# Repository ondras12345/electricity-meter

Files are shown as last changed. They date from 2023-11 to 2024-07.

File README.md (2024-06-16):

# Electricity meter
An STM32-based datalogger for electricity meters with pulse LED.

This repository contains both the PCB design files and firmware source code.

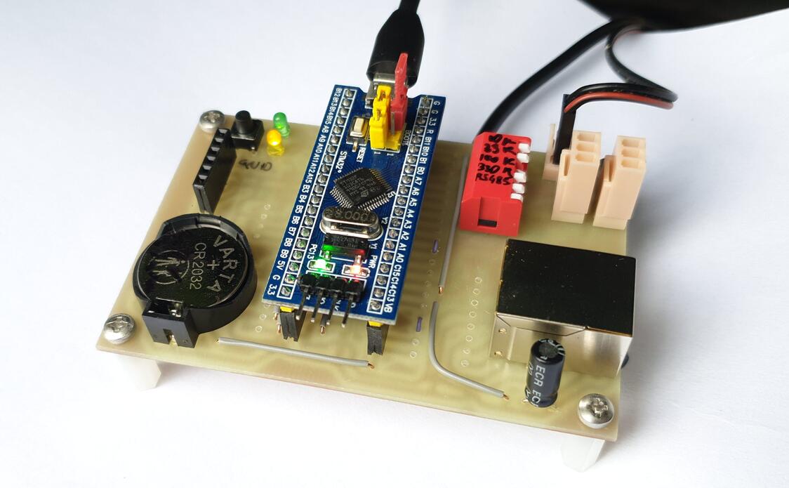
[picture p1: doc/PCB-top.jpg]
Assembled PCB

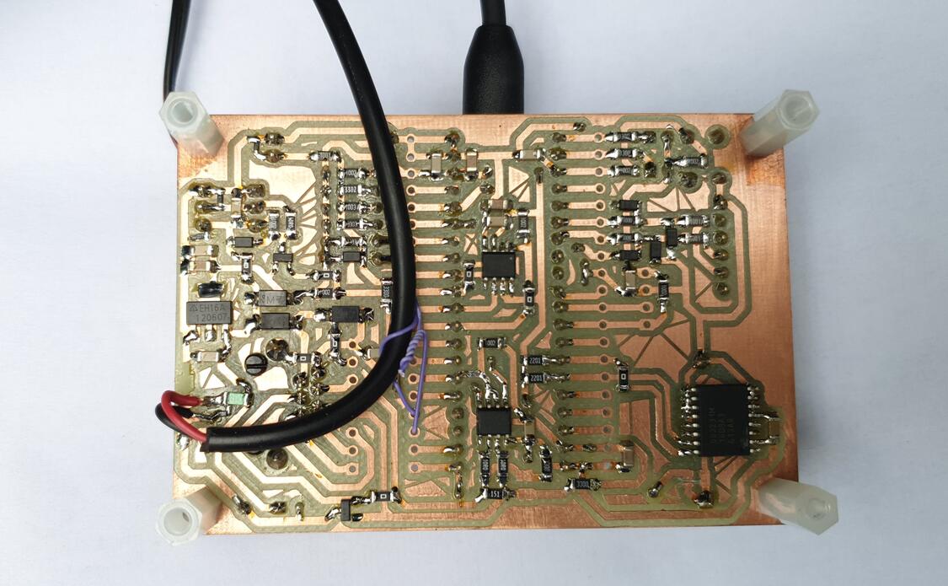
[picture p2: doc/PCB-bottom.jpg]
Bottom side of PCB


## Features
- detecting pulses of LED more than 100 mm away from the sensor,
- dynamic adjustment of bright / dark threshold,
- logging over one year of 1 minute resolution data to SPI flash,
- command line interface for debugging and reading logged data over USB CDC,
- support for RS485 communication.

## Building
### Hardware
I milled the single sided PCB on my [CNC machine](https://github.com/ondras12345/CNC).

Some notes:
- The DCF-3850N connector is only there for future-proofing. I don't currently
  use it and never tested it.
- The onewire bus connector is currently unused, but it should be easy enough
  to add DS18B20 temperature sensors.
- DS3231 RTC is necessary because the internal RTC on my STM32F103 was not
  accurate enough. Cut JP1 (battery power to STM32 VBAT) if you decide to use
  it too.
- The micro USB connector was a bad idea. I ended up replacing it with wires
  soldered directly to the board after accidentally breaking it off several
  times.

### Firmware
```sh
make help  # show available commands
make  # build
make check  # run cppcheck
```

For uploading to the STM32 via STlink, I use `tools/mkbin` and
`tools/upload_latest`.

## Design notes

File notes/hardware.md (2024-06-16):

- RTC
  - internal? (low stability)
    - DCF77 receiver?
  - external DS3231?
- UART / USB
  - USB-CDC is way faster
- 1x ADC for pulse input
  - automatic threshold - see [`automatic-threshold.ipynb`](automatic-threshold.ipynb)
- SPI flash || SD card || both
- DIP switches (pull-up value)
  - TODO make it software configurable instead? (only VCC-0.4V)
- ATmega8
  - - needs external RTC
  - - too little flash space
  - - needs 3v3 converter for SPI flash & SD card
  - + lots of them
  - USART can go faster https://arduino.stackexchange.com/questions/296/how-high-of-a-baud-rate-can-i-go-without-errors
- STM32F103
  - - more expensive
  - - power consumption?
  - - physically bigger
  - + has RTC (precision?, external crystal?)
  - + USB CDC
  - + higher ADC resolution
  - + 3v3 SD card
  - + enough flash for fully featured command line
- RS485 modbus? - would need optical isolation
  - https://github.com/arduino-libraries/ArduinoModbus
  - https://github.com/arduino-libraries/ArduinoRS485

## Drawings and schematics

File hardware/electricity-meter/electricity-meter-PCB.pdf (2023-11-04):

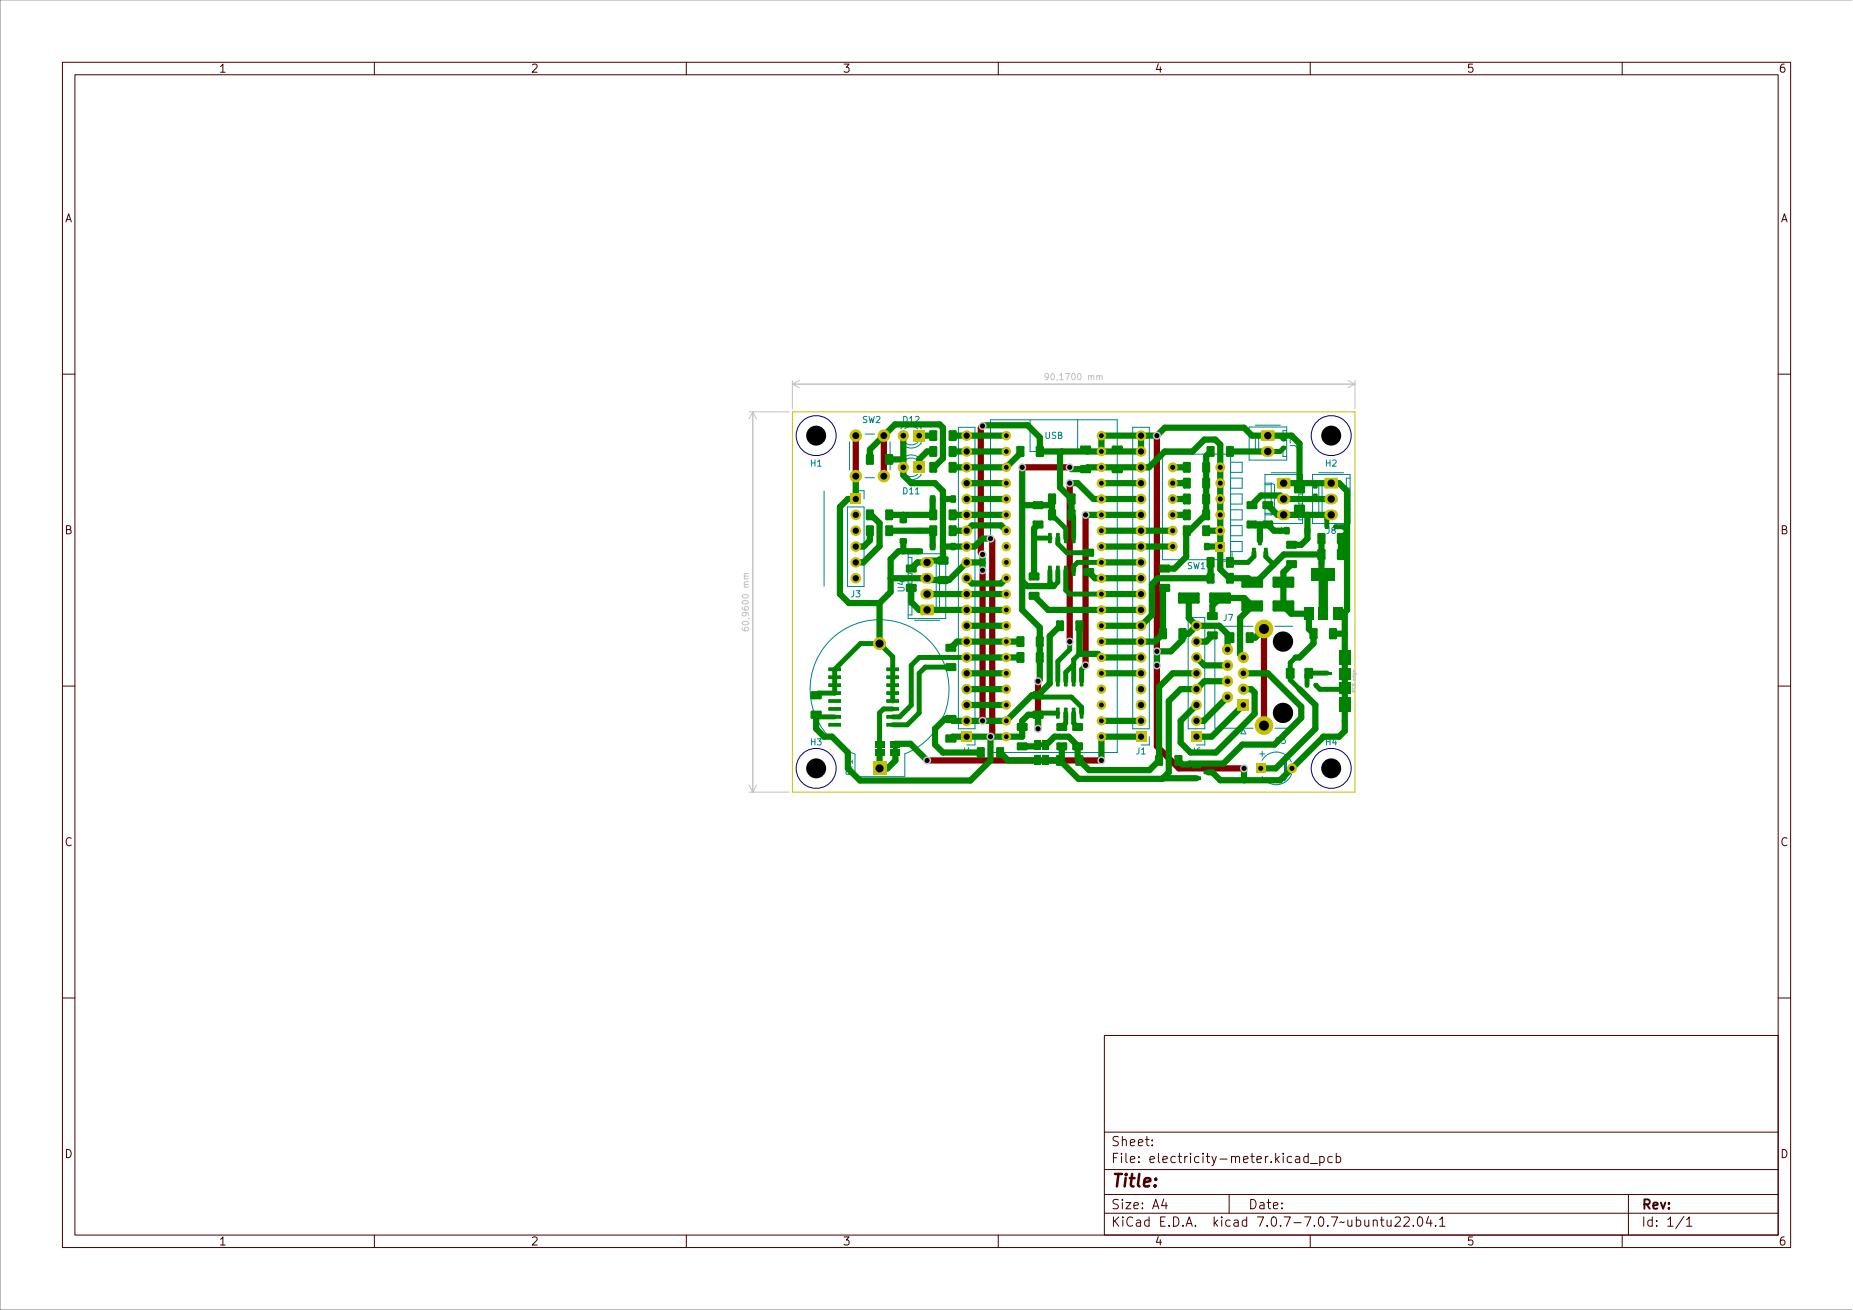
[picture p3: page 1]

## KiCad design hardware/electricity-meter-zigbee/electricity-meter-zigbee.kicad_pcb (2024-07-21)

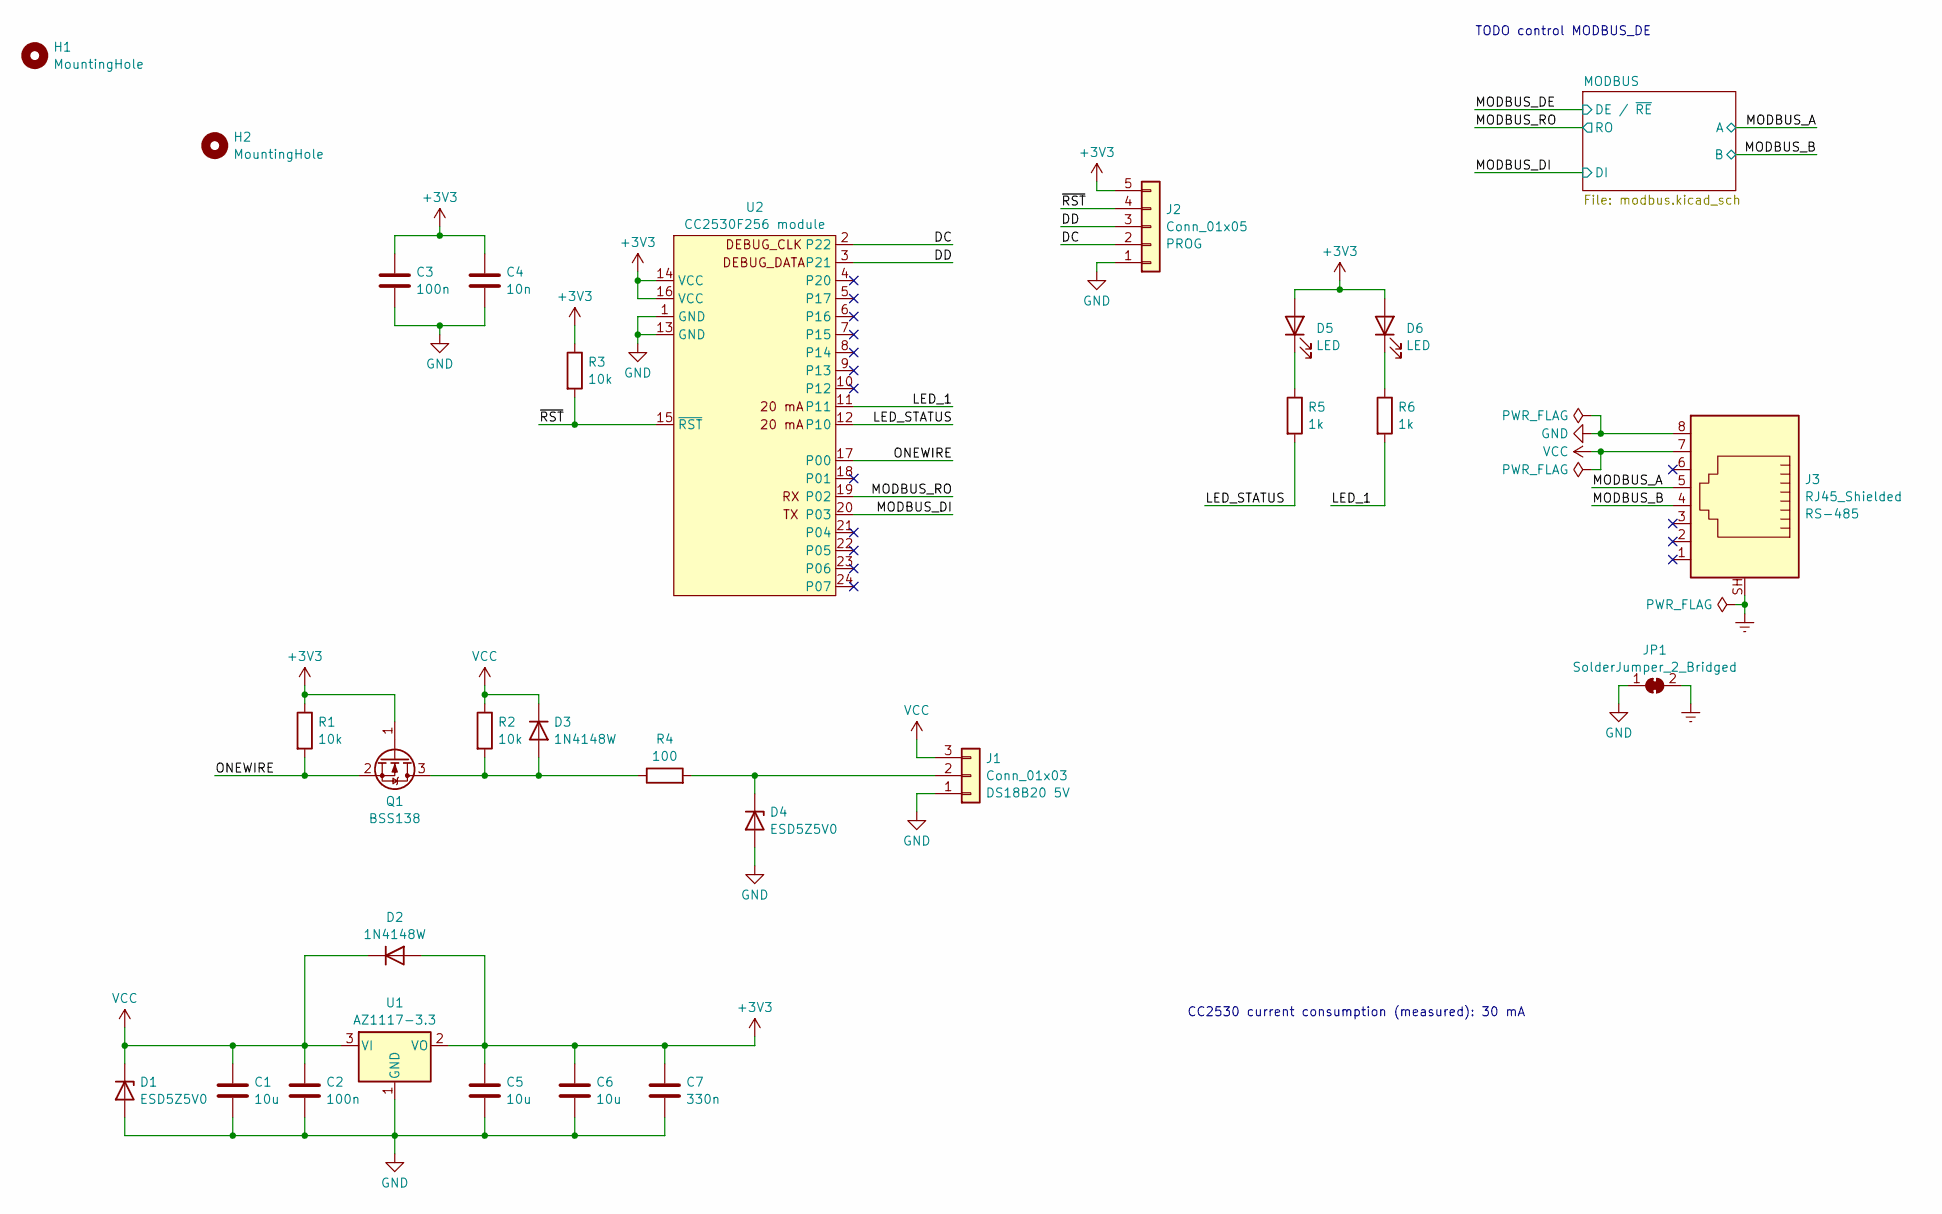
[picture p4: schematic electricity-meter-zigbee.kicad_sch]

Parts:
C1, C5, C6: 10u; C_1206_3216Metric_Pad1.33x1.80mm_HandSolder
C2, C3: 100n; C_1206_3216Metric_Pad1.33x1.80mm_HandSolder
C4: 10n; C_1206_3216Metric_Pad1.33x1.80mm_HandSolder
C7: 330n; C_1206_3216Metric_Pad1.33x1.80mm_HandSolder
D1, D4: ESD5Z5V0; D_SOD-523
D2, D3: 1N4148W; D_SOD-123
D5, D6: LED; LED_D3.0mm
H1, H2: MountingHole; MountingHole_3.2mm_M3
J1: Conn_01x03; Molex_KK-254_AE-6410-03A_1x03_P2.54mm_Vertical
J2: Conn_01x05; Molex_KK-254_AE-6410-05A_1x05_P2.54mm_Vertical
J3: RJ45_Shielded; RJ45_HALO_HFJ11-x2450HRL_Horizontal
JP1: SolderJumper_2_Bridged; SolderJumper-2_P1.3mm_Bridged_RoundedPad1.0x1.5mm
Q1: BSS138; SOT-23
R1, R2, R3: 10k; R_1206_3216Metric_Pad1.30x1.75mm_HandSolder
R4: 100; R_1206_3216Metric_Pad1.30x1.75mm_HandSolder
R5, R6: 1k; R_1206_3216Metric_Pad1.30x1.75mm_HandSolder
U1: AZ1117-3.3; SOT-223-3_TabPin2
U2: CC2530F256 module; CC2530F256_module

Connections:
+3V3: C3.1, C4.1, C5.1, C6.1, C7.1, D2.2 (A), D5.2 (A), D6.2 (A), J2.5, Q1.1 (G), R1.1, R3.1, U1.2 (VO), U2.14 (VCC), U2.16 (VCC); also elsewhere on the board
/DC: J2.2, U2.2 (P22)
/DD: J2.3, U2.3 (P21)
/LED_1: R6.2, U2.11
/LED_STATUS: R5.2, U2.12 (P10)
/MODBUS_A: J3.5; also elsewhere on the board
/MODBUS_B: J3.4; also elsewhere on the board
/MODBUS_DI: U2.20 (P03); also elsewhere on the board
/MODBUS_RO: U2.19 (P02); also elsewhere on the board
/ONEWIRE: Q1.2 (S), R1.2, U2.17 (P00)
/~RST: J2.4, R3.2, U2.15 (~RST)
Earth: J3.SH, JP1.2 (B)
GND: C1.2, C2.2, C3.2, C4.2, C5.2, C6.2, C7.2, D1.2 (A), D4.2 (A), J1.1, J2.1, J3.8, JP1.1 (A), U1.1 (GND), U2.1 (GND), U2.13 (GND); also elsewhere on the board
unnamed: D3.2 (A), Q1.3 (D), R2.2, R4.1
unnamed: D4.1 (K), J1.2, R4.2
unnamed: D5.1 (K), R5.1
unnamed: D6.1 (K), R6.1
VCC: C1.1, C2.1, D1.1 (K), D2.1 (K), D3.1 (K), J1.3, J3.7, R2.1, U1.3 (VI)

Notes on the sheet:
TODO control MODBUS_DE
CC2530 current consumption (measured): 30 mA

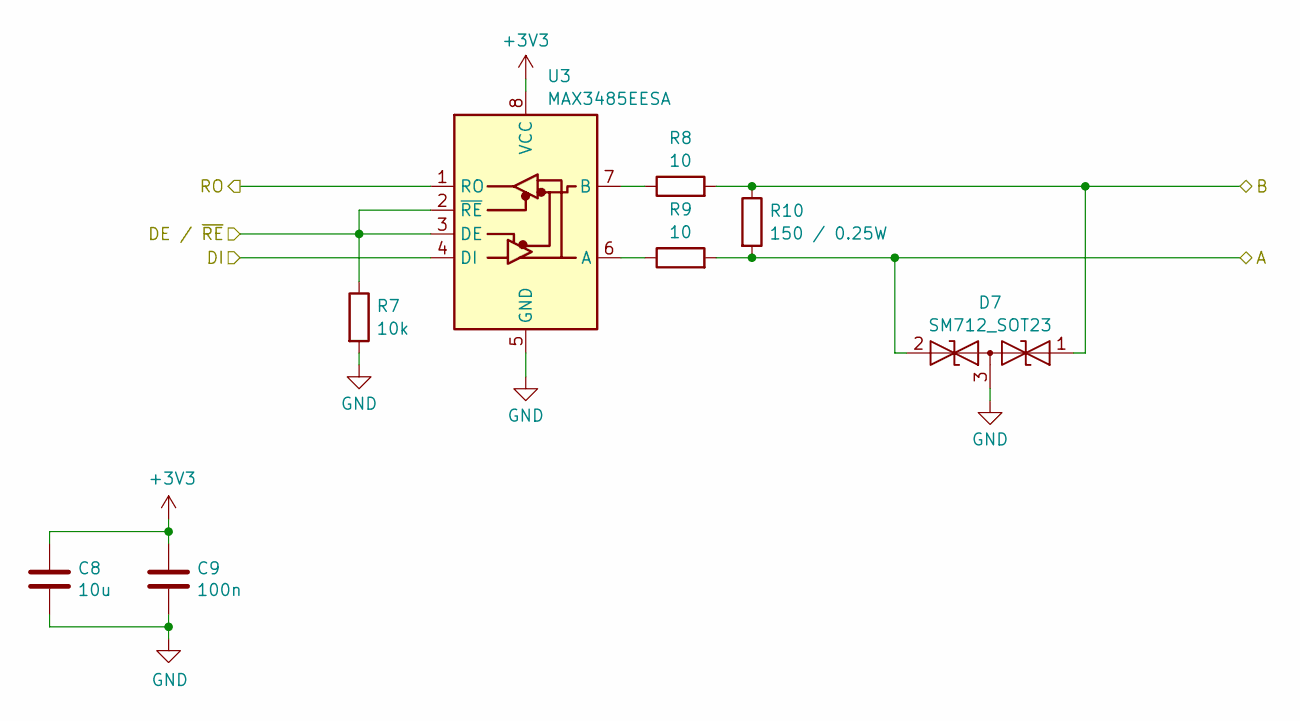
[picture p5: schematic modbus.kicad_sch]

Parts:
C8: 10u; C_1206_3216Metric_Pad1.33x1.80mm_HandSolder
C9: 100n; C_1206_3216Metric_Pad1.33x1.80mm_HandSolder
D7: SM712_SOT23; SOT-23
R7: 10k; R_1206_3216Metric_Pad1.30x1.75mm_HandSolder
R8, R9: 10; R_1206_3216Metric_Pad1.30x1.75mm_HandSolder
R10: 150 / 0.25W; R_1206_3216Metric_Pad1.30x1.75mm_HandSolder
U3: MAX3485EESA; SO-8_3.9x4.9mm_P1.27mm

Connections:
+3V3: C8.1, C9.1, U3.8 (VCC); also elsewhere on the board
/MODBUS_A: D7.2 (A2), R9.2, R10.2; also elsewhere on the board
/MODBUS_B: D7.1 (A1), R8.2, R10.1; also elsewhere on the board
/MODBUS_DE: R7.1, U3.2 (~RE), U3.3 (DE)
/MODBUS_DI: U3.4 (DI); also elsewhere on the board
/MODBUS_RO: U3.1 (RO); also elsewhere on the board
GND: C8.2, C9.2, D7.3 (common), R7.2, U3.5 (GND); also elsewhere on the board
unnamed: R9.1, U3.6 (A)
unnamed: R8.1, U3.7 (B)

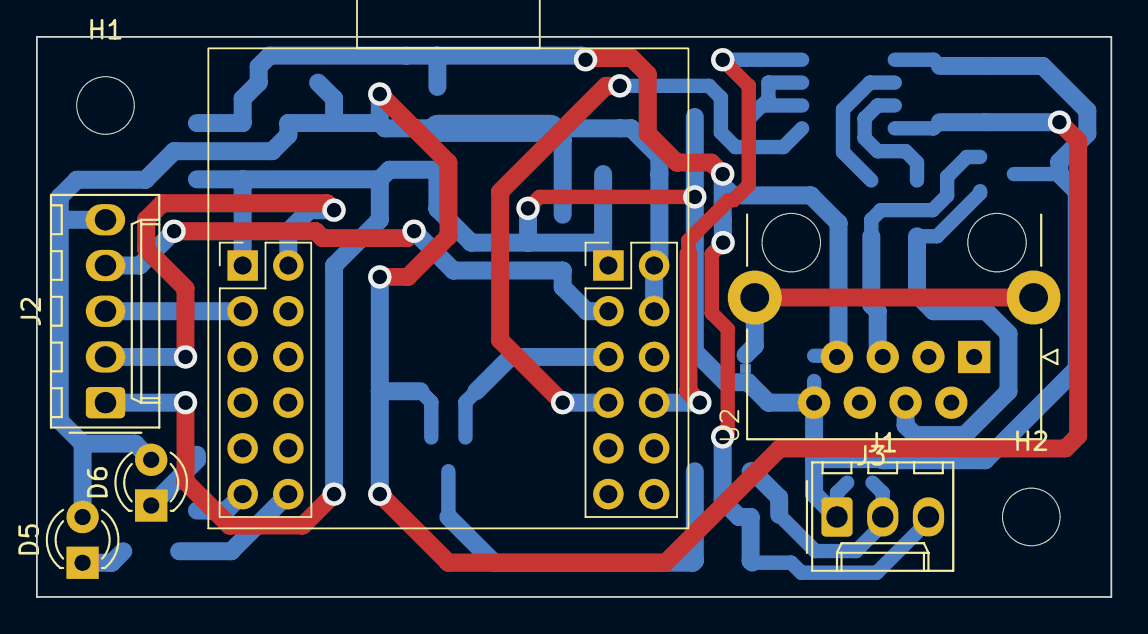
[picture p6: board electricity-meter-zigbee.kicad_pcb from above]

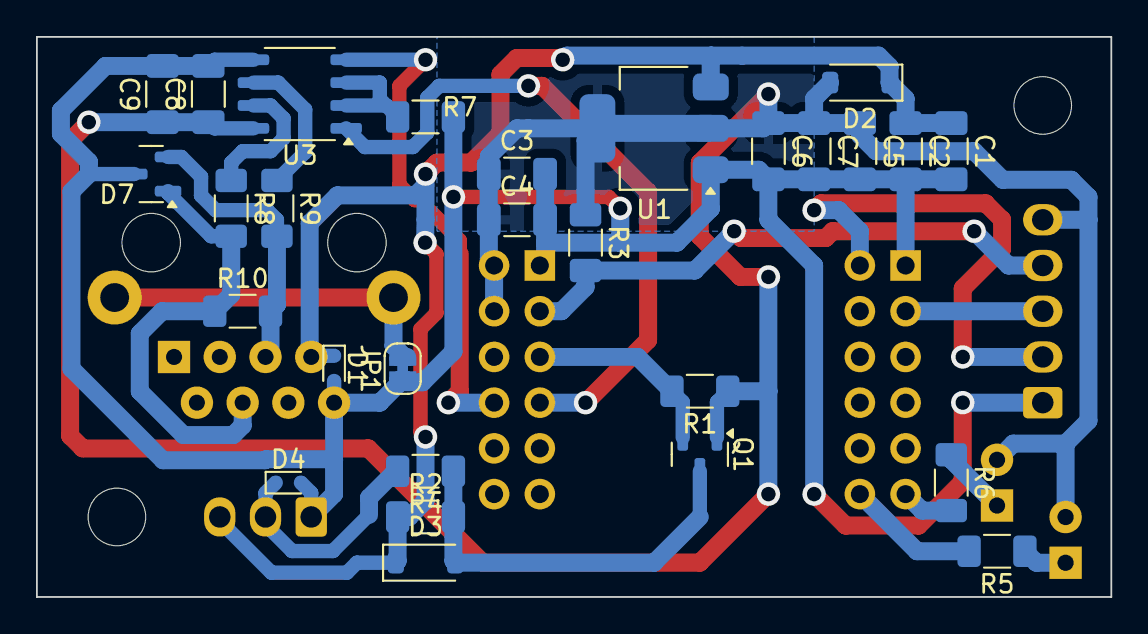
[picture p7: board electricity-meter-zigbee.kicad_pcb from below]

Board: 2 copper layers, 59.7 x 31.1 mm, 36 parts (28 on the bottom side), 21 nets.

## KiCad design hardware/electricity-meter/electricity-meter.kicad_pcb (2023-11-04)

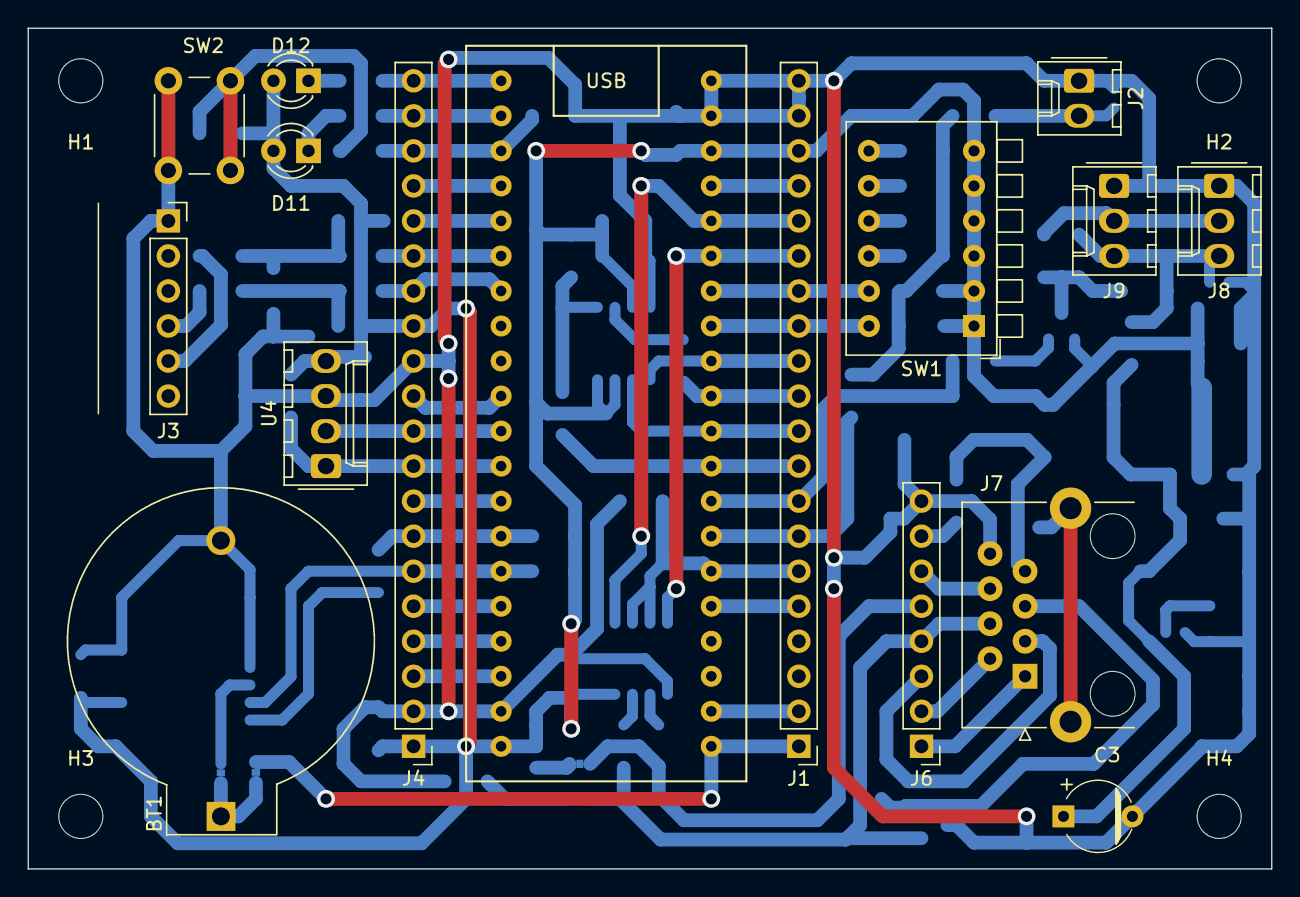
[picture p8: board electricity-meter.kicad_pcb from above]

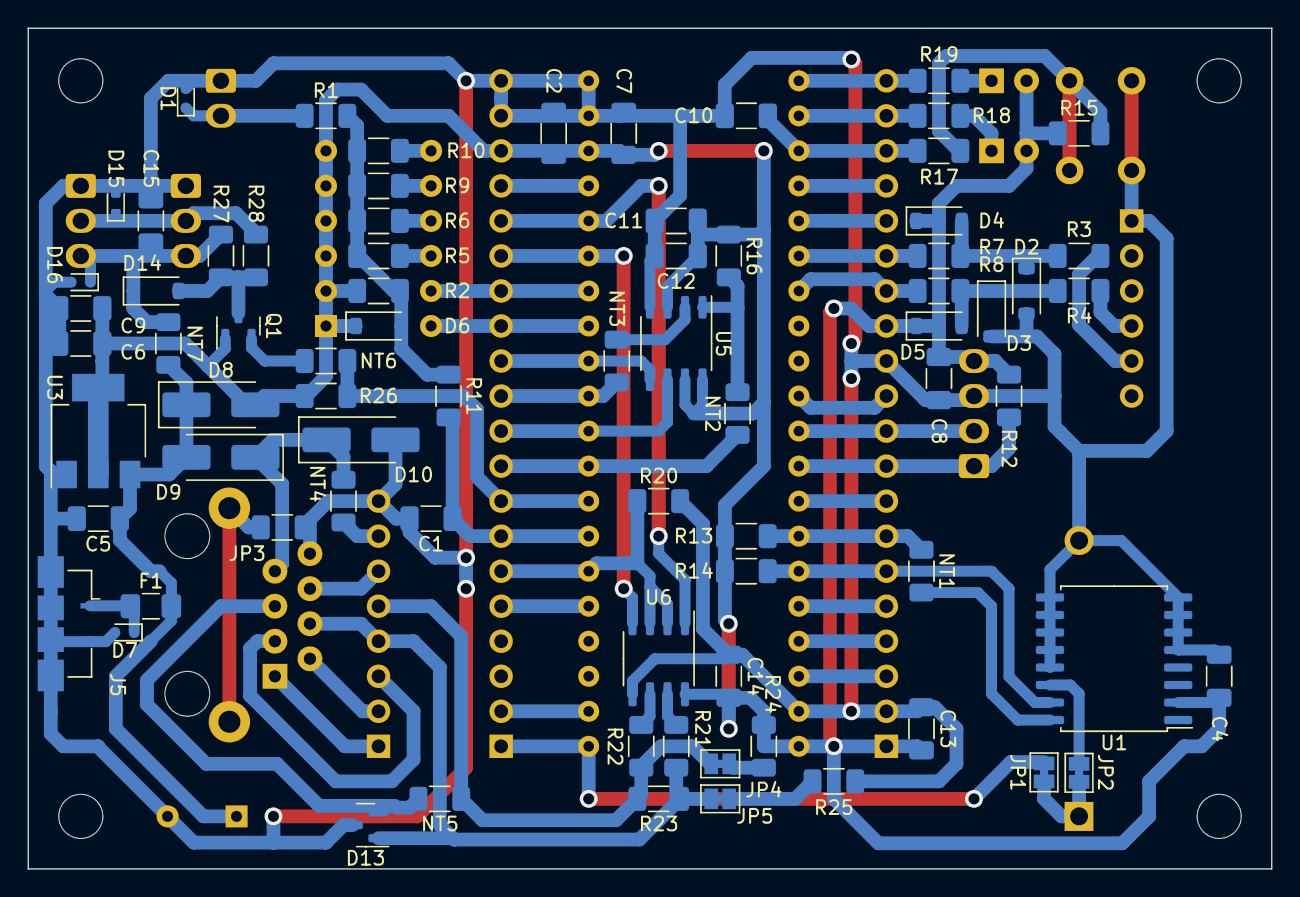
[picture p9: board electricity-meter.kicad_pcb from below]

Board: 2 copper layers, 90.2 x 61.0 mm, 95 parts (75 on the bottom side), 71 nets.

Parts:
BT1: CR2032; BatteryHolder_DS1092-04-B6P
C1: 10n; C_1206_3216Metric_Pad1.33x1.80mm_HandSolder
C2, C4, C5, C8, C10, C12, C14, C15: 100n; C_1206_3216Metric_Pad1.33x1.80mm_HandSolder
C3: 100u; CP_Radial_D5.0mm_P5.00mm
C6, C7, C11, C13: 10u; C_1206_3216Metric_Pad1.33x1.80mm_HandSolder
C9: 330n; C_1206_3216Metric_Pad1.33x1.80mm_HandSolder
D1: ESD5Z3.3T1G; D_SOD-523
D2, D3, D4, D5, D6, D14: 1N4148W; D_SOD-123
D7, D15, D16: ESD5Z5V0; D_SOD-523
D8, D9, D10: 1N4007; D_SMA_Handsoldering
D11: YELLOW; LED_D3.0mm
D12: GREEN; LED_D3.0mm
D13: SM712_SOT23; SOT-23
F1: 0ZCJ0016FF2E; Fuse_1206_3216Metric_Pad1.42x1.75mm_HandSolder
H1, H2, H3, H4: MountingHole; MountingHole_3.2mm_M3
J1, J4: Conn_01x20_Pin; PinHeader_1x20_P2.54mm_Vertical
J2: Conn_01x02_Pin; Molex_KK-254_AE-6410-02A_1x02_P2.54mm_Vertical
J3: FTDI breakout; FTDI_breakout
J5: ESB228110100Z; USB_Micro-B_Amphenol_10104110_Horizontal_power_only
J6: Conn_01x08; PinHeader_1x08_P2.54mm_Vertical
J7: RJ45_Shielded; RJ45_HALO_HFJ11-x2450HRL_Horizontal
J8, J9: Conn_01x03; Molex_KK-254_AE-6410-03A_1x03_P2.54mm_Vertical
JP1, JP2, JP4, JP5: SolderJumper_2_Bridged; SolderJumper-2_P1.3mm_Bridged_Pad1.0x1.5mm
JP3: SolderJumper_2_Bridged; R_1206_3216Metric_Pad1.30x1.75mm_HandSolder
NT1, NT2, NT3, NT4, NT5, NT6, NT7: NetTie_2; R_1206_3216Metric_Pad1.30x1.75mm_HandSolder
Q1: BSS138; SOT-23
R1, R3, R4: 1k; R_1206_3216Metric_Pad1.30x1.75mm_HandSolder
R2, R5: 330k; R_1206_3216Metric_Pad1.30x1.75mm_HandSolder
R6: 100k; R_1206_3216Metric_Pad1.30x1.75mm_HandSolder
R7, R8: 100; R_1206_3216Metric_Pad1.30x1.75mm_HandSolder
R9: 33k; R_1206_3216Metric_Pad1.30x1.75mm_HandSolder
R10, R12, R15, R16, R17, R20, R26, R27: 10k; R_1206_3216Metric_Pad1.30x1.75mm_HandSolder
R11, R18, R19, R24, R25: 330; R_1206_3216Metric_Pad1.30x1.75mm_HandSolder
R13, R14: 2k2; R_1206_3216Metric_Pad1.30x1.75mm_HandSolder
R21, R22, R28: 10; R_1206_3216Metric_Pad1.30x1.75mm_HandSolder
R23: 150 / 0.25W; R_1206_3216Metric_Pad1.30x1.75mm_HandSolder
SW1: SW_DIP_x06; SW_DIP_SPSTx06_Piano_10.8x16.8mm_W7.62mm_P2.54mm
SW2: SW_Push; SW_PUSH_6mm
U1: DS3231M; SOIC-16W_7.5x10.3mm_P1.27mm
U2: ChinaBluePill
U3: AZ1117-3.3; SOT-223-3_TabPin2
U4: DCF-3850N-800; Molex_KK-254_AE-6410-04A_1x04_P2.54mm_Vertical
U5: MX25L3233FM1; SOP-8_3.9x4.9mm_P1.27mm
U6: MAX3485EESA; SO-8_3.9x4.9mm_P1.27mm

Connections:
+3V3: C2.1, C4.1, C6.1, C7.1, C8.1, C9.1, C11.1, C12.1, C13.1, C14.1, D4.1 (K), D5.1 (K), D6.1 (K), D8.2 (A), D11.2 (A), D12.2 (A), J1.18, J4.1, J4.13, Q1.1 (G), R2.1, R12.1, R13.1, R14.1, R15.1, R16.1, R24.1, R26.1, SW1.1, SW1.2, SW1.3, SW1.4, SW1.5, SW1.6, U1.2 (VCC), U2.3V3, U3.2 (VO), U4.4 (VDD), U5.3 (~WP/SIO2), U5.7 (~HOLD/SIO3), U5.8 (VCC), U6.8 (VCC)
+5V: C3.1, C5.1, D8.1 (K), D9.2 (A), F1.2, NT7.2, U3.3 (VI)
/5V_STM: J4.3, U2.5V
/BTN_UMOUNT: C10.1, J4.18, R17.1, U2.PB14
/DCF77_DATA: J4.10, U2.PB3, U4.2 (OUT)
/DCF77_~PON: J4.9, R12.2, U2.PB4, U4.1 (~PON)
/LED_PULSE: J4.19, R18.2, U2.PB13
/LED_STATUS: J4.20, R19.2, U2.PB12
/MISO: J1.11, NT3.1, U2.PA6
/MODBUS_A: D13.2 (A2), J7.5, NT5.2
/MODBUS_A_NT: J6.5, JP4.1 (A), NT5.1, R22.2, R23.2
/MODBUS_B: D13.1 (A1), J6.4, J7.4, JP5.2 (B), R21.2, R23.1
/MODBUS_DE: J1.6, R20.1, U2.PA1, U6.2 (~RE), U6.3 (DE)
/MODBUS_DI: J1.15, U2.PB10, U6.4 (DI)
/MODBUS_RO: J1.16, U2.PB11, U6.1 (RO)
/MODBUS_VP: D9.1 (K), D10.1 (K), J7.7, NT4.2
/MOSI: J1.12, U2.PA7, U5.5 (SI/SIO0)
/NRST: J1.17, U2.NRST
/ONEWIRE: J1.8, NT6.1, R26.2, U2.PA3
/PA0: J1.5, U2.PA0
/PA2: C1.1, J1.7, R11.2, U2.PA2
/PA4: J1.9, NT2.1, U2.PA4
/PA5: J1.10, U2.PA5, U5.6 (SCLK)
/PA8: J4.16, U2.PA8
/PA9: J4.15, R7.2, U2.PA9
/PA10: J4.14, R8.2, U2.PA10
/PA15: J4.11, U2.PA15
/PB0: J1.13, SW1.12, U2.PB0
/PB1: J1.14, SW1.11, U2.PB1
/PB5: J4.8, U2.PB5
/PB6: J4.7, NT1.1, R13.2, U2.PB6
/PB7: J4.6, R14.2, U1.15 (SDA), U2.PB7
/PB8: J4.5, U2.PB8
/PB9: J4.4, U2.PB9
/PB15: J4.17, U2.PB15
/PC13: J1.2, U2.PC13
/VBAT: J1.1, JP1.2 (B), U2.VBAT
/onewire/ONEWIRE_5V: D14.2 (A), Q1.3 (D), R27.2, R28.1
Earth: J7.SH, JP3.2 (B)
GND: BT1.2 (-), C1.2, C2.2, C3.2, C4.2, C5.2, C6.2, C7.2, C8.2, C9.2, C10.2, C11.2, C12.2, C13.2, C14.2, C15.2, D1.2 (A), D2.2 (A), D3.2 (A), D7.2 (A), D10.2 (A), D13.3 (common), D15.2 (A), D16.2 (A), J1.19, J1.20, J2.1, J3.1 (GND), J4.2, J4.12, J5.5 (GND), J5.6 (Shield), J6.8, J7.8, J8.1, J9.1, JP3.1 (A), R20.2, R25.2, SW2.2, U1.5 (GND), U1.6 (GND), U1.7 (GND), U1.8 (GND), U1.9 (GND), U1.10 (GND), U1.11 (GND), U1.12 (GND), U1.13 (GND), U2.GND, U3.1 (GND), U4.3 (GND), U5.4 (GND), U6.5 (GND)
unnamed: BT1.1 (+), JP1.1 (A), JP2.1 (A)
unnamed: D1.1 (K), J2.2, R1.1
unnamed: D2.1 (K), D4.2 (A), R3.2, R7.1
unnamed: D3.1 (K), D5.2 (A), R4.2, R8.1
unnamed: D6.2 (A), R1.2, R2.2, R5.2, R6.2, R9.2, R10.2, R11.1
unnamed: D7.1 (K), F1.1, J5.1 (VBUS)
unnamed: D11.1 (K), R18.1
unnamed: D12.1 (K), R19.1
unnamed: C15.1, D14.1 (K), D16.1 (K), J8.3, J9.3, NT7.1, R27.1
unnamed: D15.1 (K), J8.2, J9.2, R28.2
unnamed: J3.5 (RX), R3.1
unnamed: J3.4 (TX), R4.1
unnamed: J6.1, J7.1
unnamed: J6.2, J7.2
unnamed: J6.3, J7.3
unnamed: J6.6, J7.6
unnamed: J6.7, NT4.1
unnamed: JP2.2 (B), U1.14 (VBAT)
unnamed: JP4.2 (B), R24.2
unnamed: JP5.1 (A), R25.1
unnamed: NT6.2, Q1.2 (S)
unnamed: R5.1, SW1.10
unnamed: R6.1, SW1.9
unnamed: R9.1, SW1.8
unnamed: R10.1, SW1.7
unnamed: R15.2, R17.2, SW2.1
unnamed: NT1.2, U1.16 (SCL)
unnamed: NT3.2, U5.2 (SO/SIO1)
unnamed: NT2.2, R16.2, U5.1 (~CS)
unnamed: R22.1, U6.6 (A)
unnamed: R21.1, U6.7 (B)

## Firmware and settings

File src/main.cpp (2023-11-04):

#include <Arduino.h>
#include <IWatchdog.h>
#include "hardware.h"
#include "rtc.h"
#include "debug.h"
#include "pulse_counter.h"
#include "cli.h"
#include "datalogger.h"


void setup()
{
    hardware_init();

    Serial.begin();

    // wait for serial to initialize
    for (uint_fast8_t i = 0; i < 8; i++)
    {
        LED_STATUS(true);
        delay(100);
        LED_STATUS(false);
        delay(100);
    }

    // 30 second WDT
    // I'm not sure how long SPI flash chip erase takes,
    // but I don't think I can set it longer than 32.768 s.
    IWatchdog.begin(30000000);

    DEBUG->println("rtc_init");
    rtc_init();
    DEBUG->println("pulse_counter_init");
    pulse_counter_init();
    DEBUG->println("datalogger_init");
    datalogger_init();
    DEBUG->println("cli_init");
    cli_init();

    LED_STATUS(true);
    DEBUG->println("boot");
    delay(500);
    LED_STATUS(false);
}


void loop()
{
    rtc_loop();
    pulse_counter_loop();
    datalogger_loop();
    cli_loop();
    IWatchdog.reload();
}

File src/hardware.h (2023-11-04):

#pragma once
#include <Arduino.h>

#define PIN_DIP_SW_1 PB0
#define PIN_DIP_SW_2 PB1

#define PIN_LED_STATUS PB12
#define PIN_LED_PULSE PB13
#define PIN_LED_FILTERED PC13

#define PIN_BTN_1 PB14

// see also platformio.ini
#define PIN_RS485_DE PA1

#define PIN_SPI_SS_FLASH PA4
#define PIN_PULSE_COUNTER PA2

#define ADC_RESOLUTION_BITS 12


// LEDs are active low
#define LED_STATUS(state) digitalWrite(PIN_LED_STATUS, !state)
#define LED_PULSE(state) digitalWrite(PIN_LED_PULSE, !state)
#define LED_FILTERED(state) digitalWrite(PIN_LED_FILTERED, !state)

#define BUTTON_1 (!digitalRead(PIN_BTN_1))
#define SWITCH_DIP_1 digitalRead(PIN_DIP_SW_1)
#define SWITCH_DIP_2 digitalRead(PIN_DIP_SW_2)

void hardware_init();

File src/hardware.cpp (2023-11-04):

#include "hardware.h"

void hardware_init()
{
    pinMode(PIN_LED_STATUS, OUTPUT);
    LED_STATUS(false);
    pinMode(PIN_LED_PULSE, OUTPUT);
    LED_PULSE(false);
    pinMode(PIN_LED_FILTERED, OUTPUT);
    LED_FILTERED(false);

    pinMode(PIN_BTN_1, INPUT);
    pinMode(PIN_DIP_SW_1, INPUT_PULLDOWN);
    pinMode(PIN_DIP_SW_2, INPUT_PULLDOWN);

    pinMode(PIN_RS485_DE, OUTPUT);
    // receive mode
    digitalWrite(PIN_RS485_DE, LOW);

    pinMode(PIN_SPI_SS_FLASH, OUTPUT);
    digitalWrite(PIN_SPI_SS_FLASH, HIGH);

    pinMode(PIN_PULSE_COUNTER, INPUT);
    analogReadResolution(ADC_RESOLUTION_BITS);
}

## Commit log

2022-12-29 [WIP] CLI; does not work
    [cli.cpp, main.cpp]
2023-01-23 Try to fix slow response of conf menu
    [main.cpp]
2023-08-20 Add notes about SPI flash
2023-09-13 Add hardware designs
    [electricity-meter.kicad_pcb, electricity-meter.kicad_sch, electricity-meter.sch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]
2023-09-15 Update hardware designs
    * LED colors
    * fix net ties excluded from ibom
    [electricity-meter.kicad_pcb, electricity-meter.kicad_sch]
2023-09-16 Increase ADC resolution
2023-09-16 Fix rtc CLI command
    [cli.cpp]
2023-09-17 Print more human-friendly numbers in CLI pulse
2023-10-06 Fix datalogger SPI flash comms
    [main.cpp]
2023-10-06 Fix time sprintf in cli.cpp
    [cli.cpp]
2023-10-06 Only turn on LEDs if button is pressed
2023-10-07 Fix RS485 report sent too often
    [cli.cpp]
2023-10-08 Add millis()-based RTC to measure LSE clock drift
    [cli.cpp]
2023-10-16 Fix program does not fit in FLASH
    [cli.cpp]
2023-10-17 Use newer framework to reduce FLASH utilization
    15.4.1: overflowed by 684 bytes
    16.0.0: Flash: [==========] 99.4% (used 65148 bytes from 65536 bytes)
    17.0.0: Flash: [==========] 99.1% (used 64932 bytes from 65536 bytes)
2023-11-04 Disable RS485 with DIP switch
    This should lower power consumption in datalogger-only mode.
2023-11-09 Add workaround for USB CDC losing data
    [cli.cpp]
2024-01-10 Fix argument parsing in cmnd_datalogger
    [cli.cpp]
2024-06-16 Update documentation
    [electricity-meter.kicad_sch, modbus.kicad_sch, onewire.kicad_sch]
2024-07-21 Update libs
    before:
    RAM: [=== ] 32.8% (used 6716 bytes from 20480 bytes)
    Flash: [==========] 99.5% (used 65196 bytes from 65536 bytes)
    ststm32:
    RAM: [=== ] 32.6% (used 6684 bytes from 20480 bytes)
    Flash: [==========] 98.2% (used 64388 bytes from 65536 bytes)
    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
2024-07-21 Improve RS485 messages & reduce power consumption
2024-07-21 Control RS485 report rate via DIP switch
2024-07-21 Add hardware designs for electricity-meter-zigbee
    [electricity-meter-zigbee.kicad_pcb, electricity-meter-zigbee.kicad_sch, modbus.kicad_sch]
2024-07-23 Add info about hardware mod
    [electricity-meter.kicad_sch]
2024-07-27 Fix RS485 message format
    [cli.cpp]
2024-07-27 Allow RS485 DIP switch change without reset
    [cli.cpp]
